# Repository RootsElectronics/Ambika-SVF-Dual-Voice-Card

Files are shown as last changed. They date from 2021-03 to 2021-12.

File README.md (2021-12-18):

# Ambika-SVF-Dual-Voice-Card
Adaptation of the Mutable Instruments Ambika SVF Voice Card in 0603 SMD, with 2 Voices per voice card

My initial prototype (verified working at 02/2021) utilised the original through hole zener diodes. On this version I have simply changed those for a surface mount equivalent. 

Will upload BOM soon, but for now:

There are a few of these out in the wild now, someone kindly noted a fix for calibration they were having on 2 out of their 3 voice cards.

To quote

"I swapped R10 and R32 to 36k and they all calibrated approximately in the middle of the range (it may be worth experimenting with the feedback cap as well I guess.... but I'm not going to !)"

Original design by émilie gillet

CC-BY-SA 3.0

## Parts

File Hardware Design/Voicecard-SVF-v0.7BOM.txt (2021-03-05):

Qty Value         Device                Package               Parts                                                                                                             Description                                                                             
4                 LED3MM                LED3MM                LED1, LED2, LED3, LED4                                                                                            LED                                                                                     
2                 M06SIP                1X06                  JP2, JP4                                                                                                          Header 6                                                                                
4   0             220OHM-0603-1/10W-1%  0603                  R61, R62, R63, R64                                                                                                220Ω resistor                                                                           
24  0.1uF         0.1UF-0603-25V-5%     0603                  C2, C4, C7, C8, C9, C13, C14, C17, C18, C22, C23, C24, C38, C39, C40, C41, C42, C43, C45, C49, C50, C51, C52, C55 0.1µF ceramic capacitors                                                                
2   1.0uF         1.0UF-0603-16V-10%    0603                  C28, C56                                                                                                          1µF ceramic capacitors                                                                  
2   100pF         100PF-0603-50V-5%     0603                  C3, C44                                                                                                           100pF/0.1nF ceramic capacitors                                                          
6   100u          CPOL-USC              PANASONIC_C           C1, C11, C27, C46, C53, C54                                                                                       POLARIZED CAPACITOR, American symbol                                                    
2   10k           10KOHM-0603-1/10W-1%  0603                  R29, R48                                                                                                          10kΩ resistor                                                                           
6   15k           15KOHM-0603-1/10W-1%  0603                  R9, R13, R19, R31, R38, R51                                                                                       15kΩ resistor                                                                           
4   18pF          18PF-0603-50V-5%      0603                  C25, C26, C36, C37                                                                                                18pF ceramic capacitors                                                                 
2   2.2k          2.2KOHM-0603-1/10W-1% 0603                  R12, R56                                                                                                          2.2kΩ resistor                                                                          
2   20MHz         CRYSTALHC49UP         HC49UP                Q3, Q4                                                                                                            CRYSTAL                                                                                 
6   220           220OHM-0603-1/10W-1%  0603                  R24, R27, R28, R53, R54, R55                                                                                      220Ω resistor                                                                           
4   220pF         270PF-0603-50V-5%     0603                  C10, C12, C30, C31                                                                                                270pF/0.27nF ceramic capacitors                                                         
2   330k          330KOHM-0603-1/10W-1% 0603                  R22, R46                                                                                                          330kΩ resistor                                                                          
24  33k           33KOHM-0603-1/10W-1%  0603                  R2, R5, R6, R7, R8, R10, R11, R14, R17, R18, R20, R21, R32, R34, R35, R36, R37, R39, R40, R45, R47, R57, R58, R59 33kΩ resistor                                                                           
2   33nF          33NF-0603-50V-10%     0603                  C19, C29                                                                                                          33nF ceramic capacitors                                                                 
4   4.7u          CPOL-USA              PANASONIC_A           C20, C21, C47, C48                                                                                                POLARIZED CAPACITOR, American symbol                                                    
14  470           470OHM-0603-1/10W-1%  0603                  R3, R4, R15, R16, R25, R26, R30, R41, R42, R43, R44, R49, R50, R60                                                470Ω resistor                                                                           
2   47k           47KOHM-0603-1/10W-1%  0603                  R1, R52                                                                                                           47kΩ resistor                                                                           
8   560pF         560PF-0603-50V-5%     0603                  C5, C6, C15, C16, C32, C33, C34, C35                                                                              0.56nF/560pF ceramic capacitors                                                         
2   5k            R-TRIMM3296P          RTRIM3296P            R23, R33                                                                                                          Trimm resistor                                                                          
2   ATMEGA328P-AU ATMEGA328P-AU         QFP80P900X900X120-32N U1, U3                                                                                                            ATmega Series 20 MHz 32 KB Flash 2 KB SRAM 8-Bit Microcontroller - TQFP-32 Check prices 
2   AVR_ISP       AVR_SPI_PRG_6PTH      2X3                   ISP_A, ISP_B                                                                                                      AVR ISP 6 Pin                                                                           
4   BSS138        BSS138                SOT95P240X111-3N      Q1, Q2, Q5, Q6                                                                                                    N-Channel 50V 220mA (Ta) 360mW (Ta) Surface Mount SOT-23-3  Check prices                
2   CD4052BM      CD4052BM              SOIC127P600X175-16N   U2, U4                                                                                                            Check prices                                                                            
2   MCP4822-E/SN  MCP4822-E/SN          SOIC127P599X175-8N    U$7, U7                                                                                                           Check prices                                                                            
4   MMSZ3V6T1G    MMSZ3V6T1G            SOD3716X135N          Z3, Z4, Z5, Z6                                                                                                    500 mW 3.6 V +/-5% ZenerDiodeVoltage Regulator                                          
2   MMSZ4V7T1G    MMSZ4V7T1G            SOD3716X135N          Z1, Z2                                                                                                            500 mW, 4.7 V +/-5% ZenerDiodeVoltage Regulator                                         
2   TL072         TL072_SMD             SO08                  IC1, IC6                                                                                                          Generic Dual Op Amp                                                                     
2   TL074         TL074_SMD             SO14                  IC3, IC5                                                                                                          Generic Quad Op Amp                                                                     
2   V2164D        SSM2164S              SOIC16N               IC2, IC4

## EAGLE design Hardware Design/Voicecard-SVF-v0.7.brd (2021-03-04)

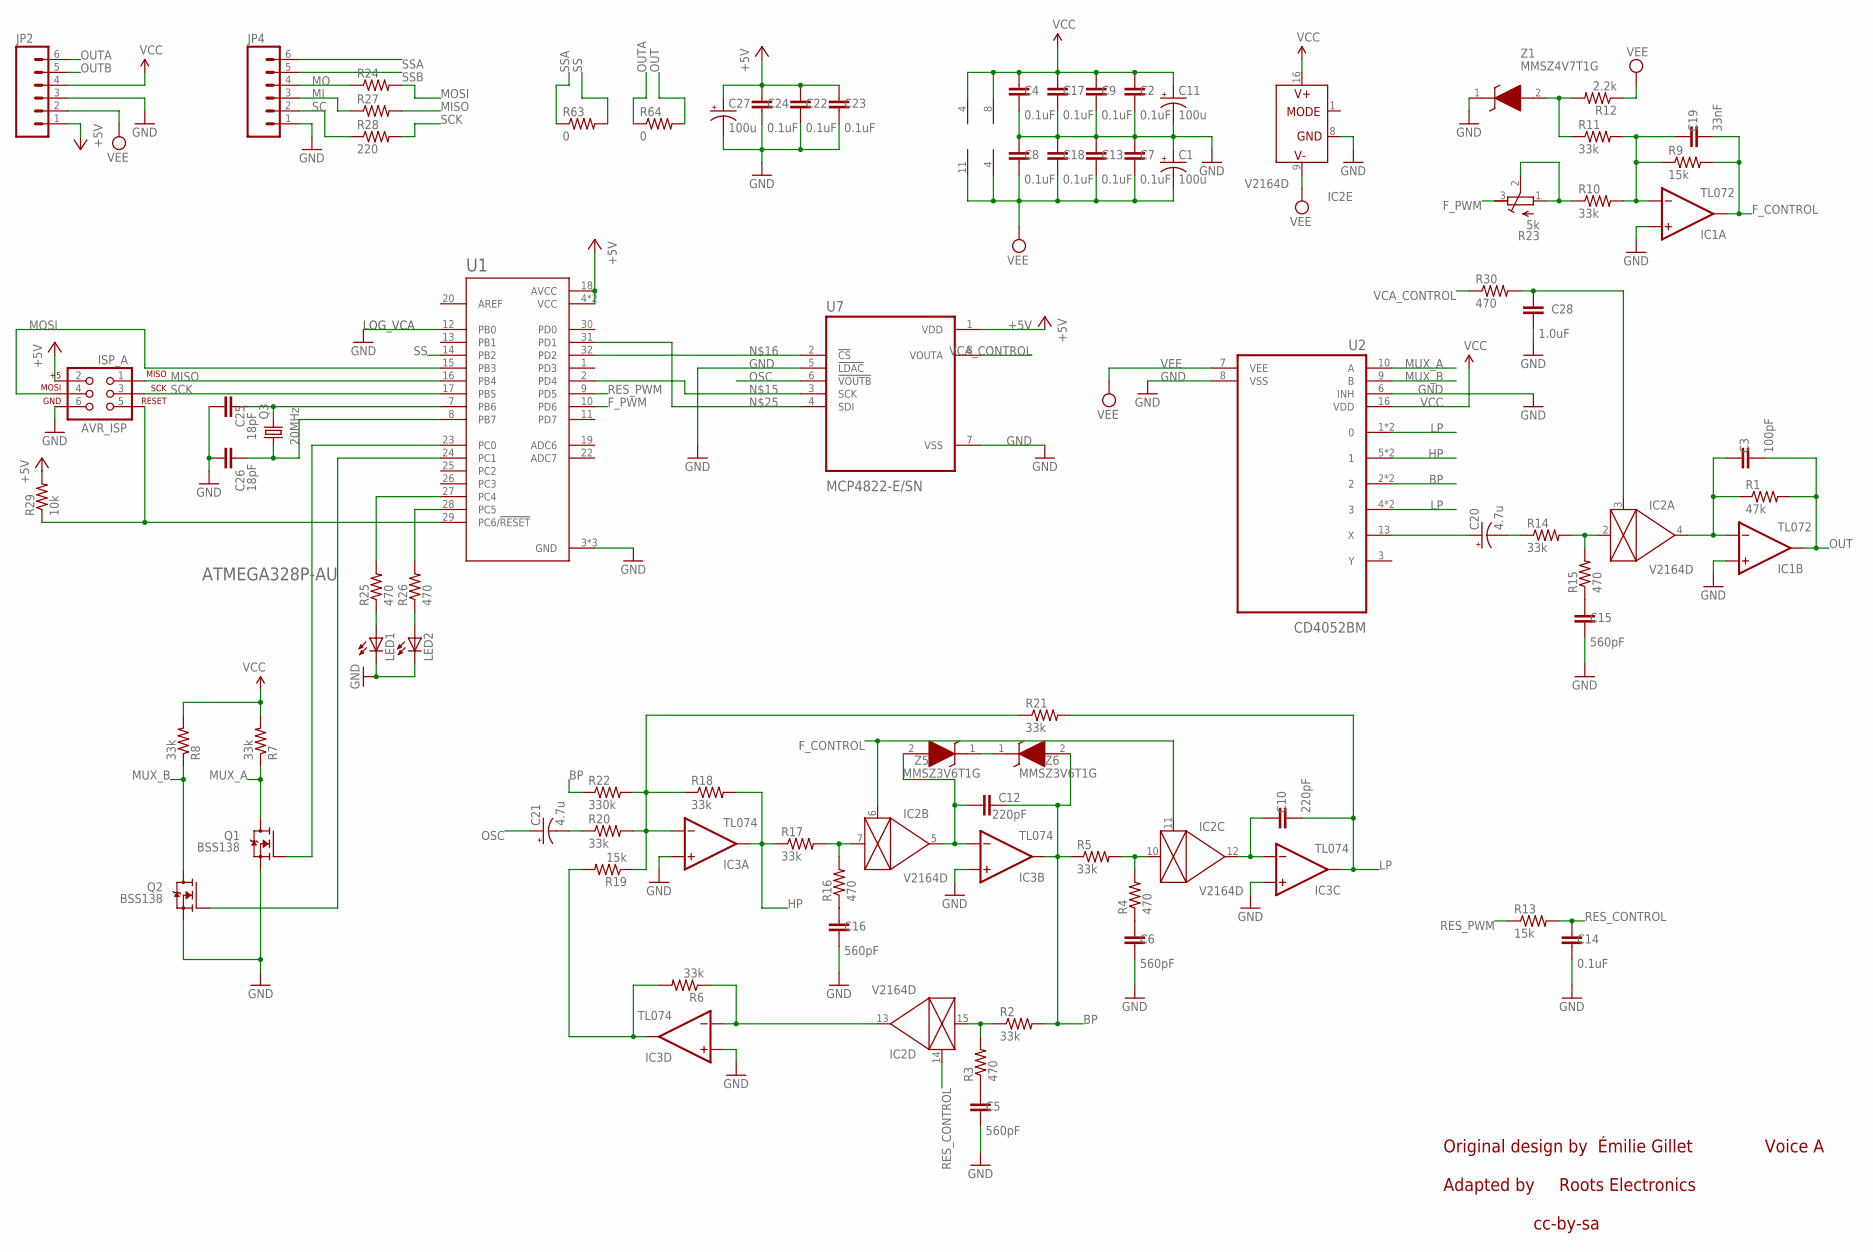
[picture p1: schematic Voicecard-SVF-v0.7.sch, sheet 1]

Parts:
C1, C11, C27: 100u; PANASONIC_C
C2, C4, C7, C8, C9, C13, C14, C17, C18, C22, C23, C24: 0.1uF; 0603
C3: 100pF; 0603
C5, C6, C15, C16: 560pF; 0603
C10, C12: 220pF; 0603
C19: 33nF; 0603
C20, C21: 4.7u; PANASONIC_A
C25, C26: 18pF; 0603
C28: 1.0uF; 0603
IC1: TL072; SO08
IC2: V2164D; SOIC16N
IC3: TL074; SO14
ISP_A: AVR_ISP; 2X3
JP2, JP4: M06SIP; 1X06
LED1, LED2: LED3MM
Q1, Q2: BSS138; SOT95P240X111-3N
Q3: 20MHz; HC49UP
R1: 47k; 0603
R2, R5, R6, R7, R8, R10, R11, R14, R17, R18, R20, R21: 33k; 0603
R3, R4, R15, R16, R25, R26, R30: 470; 0603
R9, R13, R19: 15k; 0603
R12: 2.2k; 0603
R22: 330k; 0603
R23: 5k; RTRIM3296P
R24, R27, R28: 220; 0603
R29: 10k; 0603
R63, R64: 0; 0603
U1: ATMEGA328P-AU; QFP80P900X900X120-32N
U2: CD4052BM; SOIC127P600X175-16N
U7: MCP4822-E/SN; SOIC127P599X175-8N
Z1: MMSZ4V7T1G; SOD3716X135N
Z5, Z6: MMSZ3V6T1G; SOD3716X135N

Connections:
+5V: C22.1, C23.1, C24.1, C27.+, ISP_A.2, JP2.1, R29.2, U1.4 (VCC), U1.6 (VCC), U1.18 (AVCC), U7.1 (VDD); also elsewhere on the board
BP: C12.2, IC3.7 (OUT), R2.2, R5.1, R22.1, U2.2, U2.15 (2), Z6.2 (A)
F_CONTROL: C19.2, IC1.1 (OUT), IC2.6 (CTRL), IC2.11 (CTRL), R9.2
F_PWM: R23.3 (A), U1.10 (PD6)
GND: C1.+, C2.2, C4.2, C5.2, C6.2, C7.1, C8.1, C9.2, C11.-, C13.1, C14.2, C15.2, C16.2, C17.2, C18.1, C22.2, C23.2, C24.2, C25.1, C26.1, C27.-, C28.2, IC1.3 (+IN), IC1.5 (+IN), IC2.8 (GND), IC3.3 (+IN), IC3.5 (+IN), IC3.10 (+IN), IC3.12 (+IN), ISP_A.6, JP2.3, JP4.1, LED1.K (C), LED2.K (C), Q1.2 (S), Q2.2 (S), U1.3 (GND), U1.5 (GND), U1.12 (PB0), U1.21 (GND), U2.6 (INH), U2.8 (VSS), U7.5 (!LDAC), U7.7 (VSS), Z1.1 (K); also elsewhere on the board
HP: IC3.1 (OUT), R17.1, R18.2, U2.5 (1), U2.14 (1)
LEDS0: R25.2, U1.27 (PC4)
LP: C10.2, IC3.8 (OUT), R21.2, U2.1 (0), U2.4 (3), U2.11 (3), U2.12 (0)
MI: JP4.3, R27.1; also elsewhere on the board
MISO: ISP_A.1, R27.2, U1.16 (PB4)
MO: JP4.4, R24.1; also elsewhere on the board
MOSI: ISP_A.4, R24.2, U1.15 (PB3)
MUX_A: Q1.3 (D), R7.1, U2.10 (A)
MUX_B: Q2.3 (D), R8.1, U2.9 (B)
unnamed: C21.-, R20.1
unnamed: C20.+, U2.13 (X)
unnamed: Q1.1 (G), U1.23 (PC0)
unnamed: C20.-, R14.1
unnamed: Q2.1 (G), U1.24 (PC1)
unnamed: LED1.A, R25.1
unnamed: R11.1, R12.2, Z1.2 (A)
unnamed: LED2.A, R26.1
unnamed: R26.2, U1.28 (PC5)
unnamed: IC3.2 (-IN), R18.1, R19.1, R20.2, R21.1, R22.2
unnamed: U1.2 (PD4), U7.3 (SCK)
unnamed: U1.32 (PD2), U7.2 (!CS)
unnamed: C6.1, R4.1
unnamed: C12.1, IC2.5 (OUT), IC3.6 (-IN), Z5.2 (A)
unnamed: IC2.15 (IN), R2.1, R3.2
unnamed: ISP_A.5, R29.1, U1.29 (PC6/!RESET)
unnamed: U1.31 (PD1), U7.4 (SDI)
unnamed: IC2.10 (IN), R4.2, R5.2
unnamed: C5.1, R3.1
unnamed: C10.1, IC2.12 (OUT), IC3.9 (-IN)
unnamed: IC2.7 (IN), R16.2, R17.2
unnamed: C16.1, R16.1
unnamed: IC2.13 (OUT), IC3.13 (-IN), R6.1
unnamed: C19.1, IC1.2 (-IN), R9.1, R10.2, R11.2
unnamed: R10.1, R23.1 (E), R23.2 (S)
unnamed: IC3.14 (OUT), R6.2, R19.2
unnamed: Z5.1 (K), Z6.1 (K)
unnamed: C15.1, R15.1
unnamed: IC2.2 (IN), R14.2, R15.2
unnamed: C3.1, IC1.6 (-IN), IC2.4 (OUT), R1.1
unnamed: C26.2, Q3.1, U1.8 (PB7)
unnamed: C25.2, Q3.2, U1.7 (PB6)
NET55: C28.1, IC2.3 (CTRL), R30.2
OSC: C21.+, U7.6 (!VOUTB)
OUT: C3.2, IC1.7 (OUT), R1.2, R64.2
OUTA: JP2.6, R64.1
OUTB: JP2.5; also elsewhere on the board
RES_CONTROL: C14.1, IC2.14 (CTRL), R13.2
RES_PWM: R13.1, U1.9 (PD5)
SC: JP4.2, R28.1; also elsewhere on the board
SCK: ISP_A.3, R28.2, U1.17 (PB5)
SS: R63.2, U1.14 (PB2)
SSA: JP4.6, R63.1
SSB: JP4.5; also elsewhere on the board
VCA_CONTROL: R30.1, U7.8 (VOUTA)
VCC: C2.1, C4.1, C9.1, C11.+, C17.1, IC1.8 (V+), IC2.16 (V+), IC3.4 (V+), JP2.4, R7.2, R8.2, U2.16 (VDD); also elsewhere on the board
VEE: C1.-, C7.2, C8.2, C13.2, C18.2, IC1.4 (V-), IC2.9 (V-), IC3.11 (V-), JP2.2, R12.1, U2.7 (VEE); also elsewhere on the board

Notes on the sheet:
Original design by
Émilie Gillet
LOG_VCA
Voice A
cc-by-sa
Adapted by
Roots Electronics

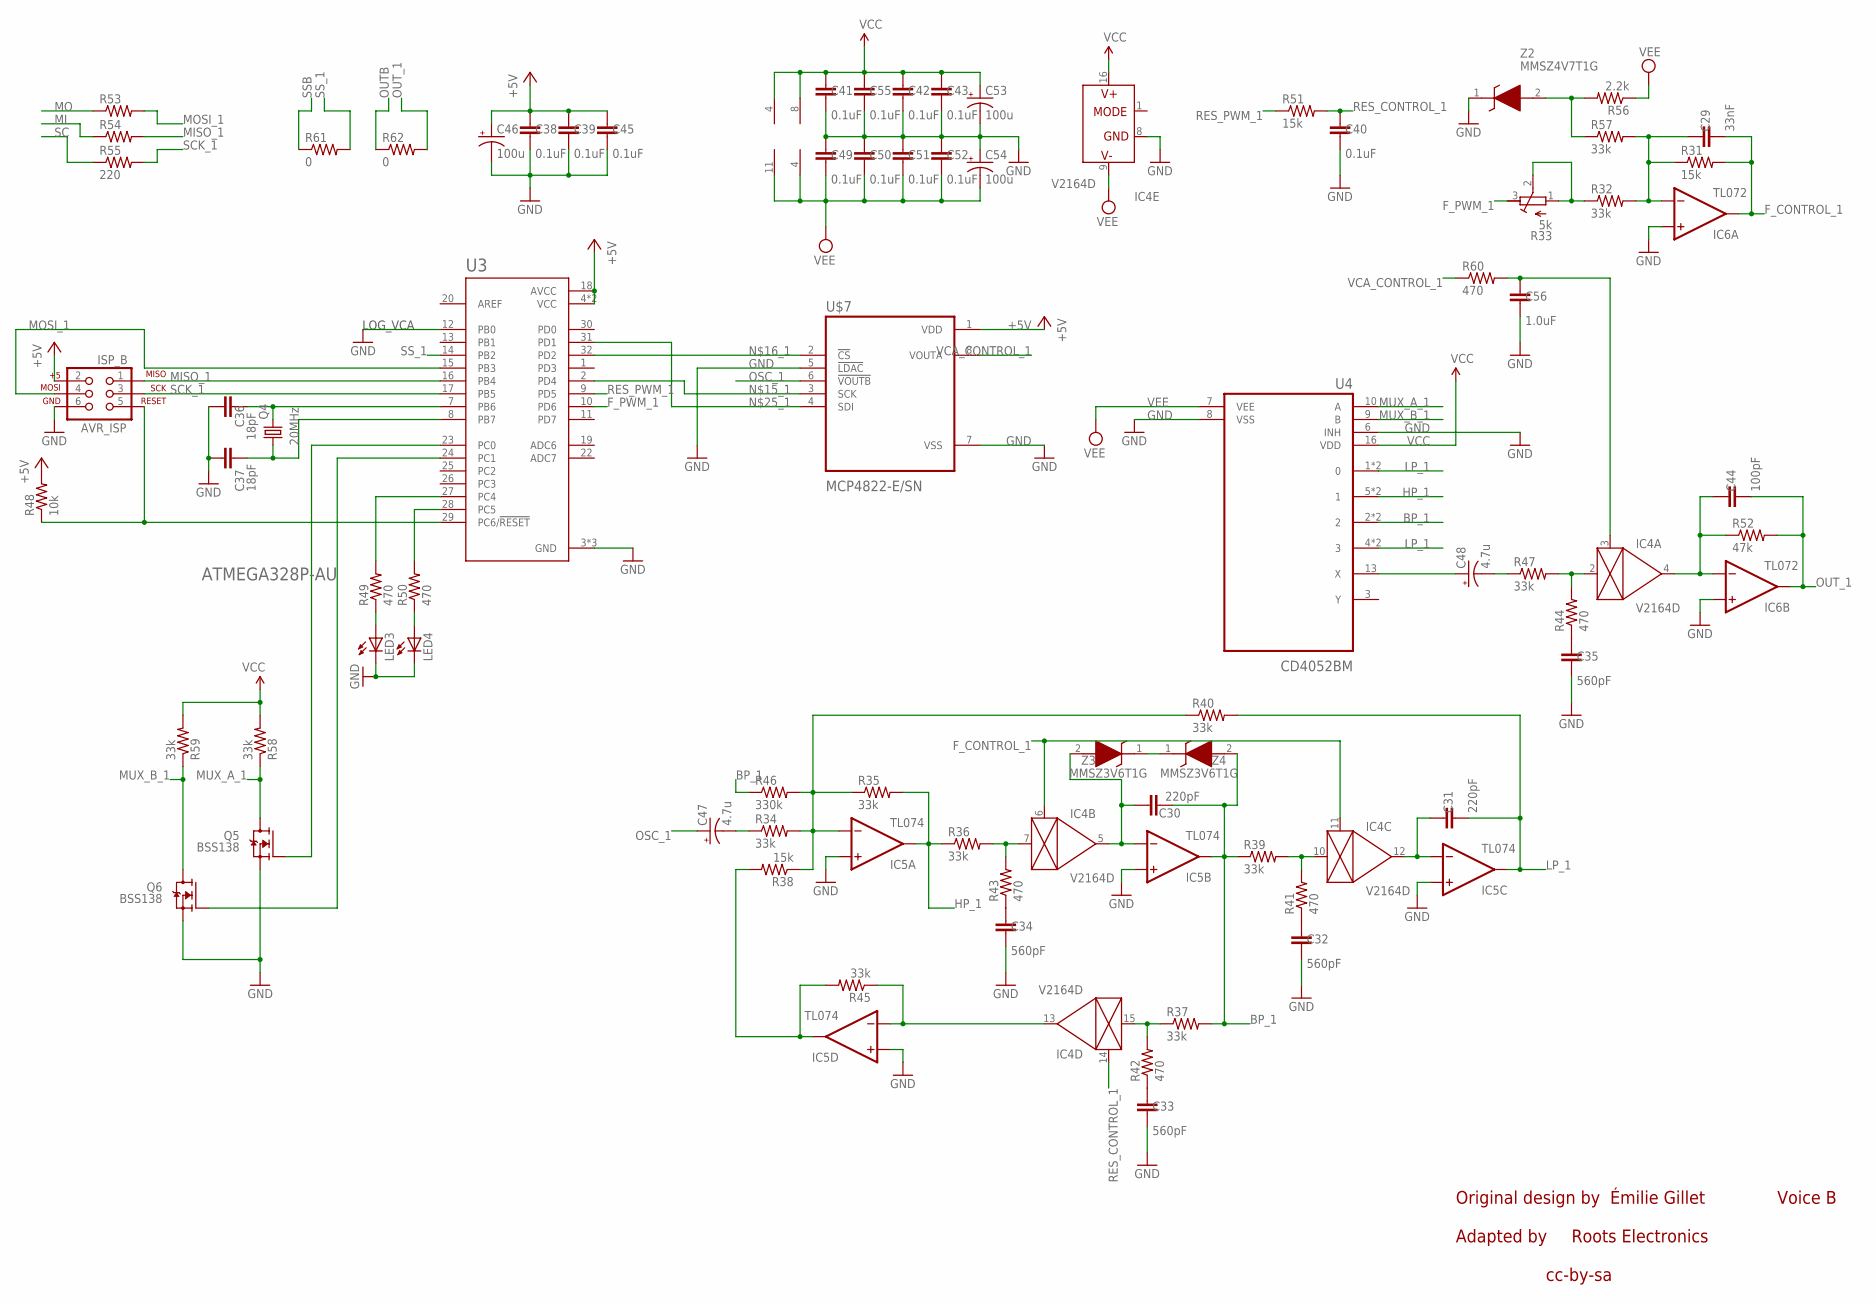
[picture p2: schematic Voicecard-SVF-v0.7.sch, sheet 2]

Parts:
C29: 33nF; 0603
C30, C31: 220pF; 0603
C32, C33, C34, C35: 560pF; 0603
C36, C37: 18pF; 0603
C38, C39, C40, C41, C42, C43, C45, C49, C50, C51, C52, C55: 0.1uF; 0603
C44: 100pF; 0603
C46, C53, C54: 100u; PANASONIC_C
C47, C48: 4.7u; PANASONIC_A
C56: 1.0uF; 0603
IC4: V2164D; SOIC16N
IC5: TL074; SO14
IC6: TL072; SO08
ISP_B: AVR_ISP; 2X3
LED3, LED4: LED3MM
Q4: 20MHz; HC49UP
Q5, Q6: BSS138; SOT95P240X111-3N
R31, R38, R51: 15k; 0603
R32, R34, R35, R36, R37, R39, R40, R45, R47, R57, R58, R59: 33k; 0603
R33: 5k; RTRIM3296P
R41, R42, R43, R44, R49, R50, R60: 470; 0603
R46: 330k; 0603
R48: 10k; 0603
R52: 47k; 0603
R53, R54, R55: 220; 0603
R56: 2.2k; 0603
R61, R62: 0; 0603
U3: ATMEGA328P-AU; QFP80P900X900X120-32N
U4: CD4052BM; SOIC127P600X175-16N
U$7: MCP4822-E/SN; SOIC127P599X175-8N
Z2: MMSZ4V7T1G; SOD3716X135N
Z3, Z4: MMSZ3V6T1G; SOD3716X135N

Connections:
+5V: C38.1, C39.1, C45.1, C46.+, ISP_B.2, R48.2, U3.4 (VCC), U3.6 (VCC), U3.18 (AVCC), U$7.1 (VDD); also elsewhere on the board
BP_1: C30.2, IC5.7 (OUT), R37.2, R39.1, R46.1, U4.2, U4.15 (2), Z4.2 (A)
F_CONTROL_1: C29.2, IC4.6 (CTRL), IC4.11 (CTRL), IC6.1 (OUT), R31.2
F_PWM_1: R33.3 (A), U3.10 (PD6)
GND: C32.2, C33.2, C34.2, C35.2, C36.1, C37.1, C38.2, C39.2, C40.2, C41.2, C42.2, C43.2, C45.2, C46.-, C49.1, C50.1, C51.1, C52.1, C53.-, C54.+, C55.2, C56.2, IC4.8 (GND), IC5.3 (+IN), IC5.5 (+IN), IC5.10 (+IN), IC5.12 (+IN), IC6.3 (+IN), IC6.5 (+IN), ISP_B.6, LED3.K (C), LED4.K (C), Q5.2 (S), Q6.2 (S), U3.3 (GND), U3.5 (GND), U3.12 (PB0), U3.21 (GND), U4.6 (INH), U4.8 (VSS), U$7.5 (!LDAC), U$7.7 (VSS), Z2.1 (K); also elsewhere on the board
HP_1: IC5.1 (OUT), R35.2, R36.1, U4.5 (1), U4.14 (1)
LEDS1_1: R49.2, U3.27 (PC4)
LP_1: C31.2, IC5.8 (OUT), R40.2, U4.1 (0), U4.4 (3), U4.11 (3), U4.12 (0)
MI: R54.1; also elsewhere on the board
MISO_1: ISP_B.1, R54.2, U3.16 (PB4)
MO: R53.1; also elsewhere on the board
MOSI_1: ISP_B.4, R53.2, U3.15 (PB3)
MUX_A_1: Q5.3 (D), R58.1, U4.10 (A)
MUX_B_1: Q6.3 (D), R59.1, U4.9 (B)
unnamed: C29.1, IC6.2 (-IN), R31.1, R32.2, R57.2
unnamed: R32.1, R33.1 (E), R33.2 (S)
unnamed: C44.1, IC4.4 (OUT), IC6.6 (-IN), R52.1
unnamed: IC5.2 (-IN), R34.2, R35.1, R38.1, R40.1, R46.2
unnamed: U3.2 (PD4), U$7.3 (SCK)
unnamed: U3.32 (PD2), U$7.2 (!CS)
unnamed: C30.1, IC4.5 (OUT), IC5.6 (-IN), Z3.2 (A)
unnamed: IC4.10 (IN), R39.2, R41.2
unnamed: C31.1, IC4.12 (OUT), IC5.9 (-IN)
unnamed: C32.1, R41.1
unnamed: U3.31 (PD1), U$7.4 (SDI)
unnamed: C33.1, R42.1
unnamed: IC4.7 (IN), R36.2, R43.2
unnamed: C34.1, R43.1
unnamed: C35.1, R44.1
unnamed: IC4.2 (IN), R44.2, R47.2
unnamed: IC4.15 (IN), R37.1, R42.2
unnamed: IC4.13 (OUT), IC5.13 (-IN), R45.1
unnamed: IC5.14 (OUT), R38.2, R45.2
unnamed: Z3.1 (K), Z4.1 (K)
unnamed: C47.-, R34.1
unnamed: C48.-, R47.1
unnamed: C37.2, Q4.1, U3.8 (PB7)
unnamed: C36.2, Q4.2, U3.7 (PB6)
unnamed: LED3.A, R49.1
unnamed: LED4.A, R50.1
unnamed: R50.2, U3.28 (PC5)
unnamed: R56.2, R57.1, Z2.2 (A)
unnamed: ISP_B.5, R48.1, U3.29 (PC6/!RESET)
unnamed: Q5.1 (G), U3.23 (PC0)
unnamed: Q6.1 (G), U3.24 (PC1)
unnamed: C48.+, U4.13 (X)
NET1: C56.1, IC4.3 (CTRL), R60.2
OSC_1: C47.+, U$7.6 (!VOUTB)
OUTB: R62.1; also elsewhere on the board
OUT_1: C44.2, IC6.7 (OUT), R52.2, R62.2
RES_CONTROL_1: C40.1, IC4.14 (CTRL), R51.2
RES_PWM_1: R51.1, U3.9 (PD5)
SC: R55.1; also elsewhere on the board
SCK_1: ISP_B.3, R55.2, U3.17 (PB5)
SSB: R61.1; also elsewhere on the board
SS_1: R61.2, U3.14 (PB2)
VCA_CONTROL_1: R60.1, U$7.8 (VOUTA)
VCC: C41.1, C42.1, C43.1, C53.+, C55.1, IC4.16 (V+), IC5.4 (V+), IC6.8 (V+), R58.2, R59.2, U4.16 (VDD); also elsewhere on the board
VEE: C49.2, C50.2, C51.2, C52.2, C54.-, IC4.9 (V-), IC5.11 (V-), IC6.4 (V-), R56.1, U4.7 (VEE); also elsewhere on the board

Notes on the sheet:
LOG_VCA
Voice B
Original design by
Émilie Gillet
cc-by-sa
Adapted by
Roots Electronics

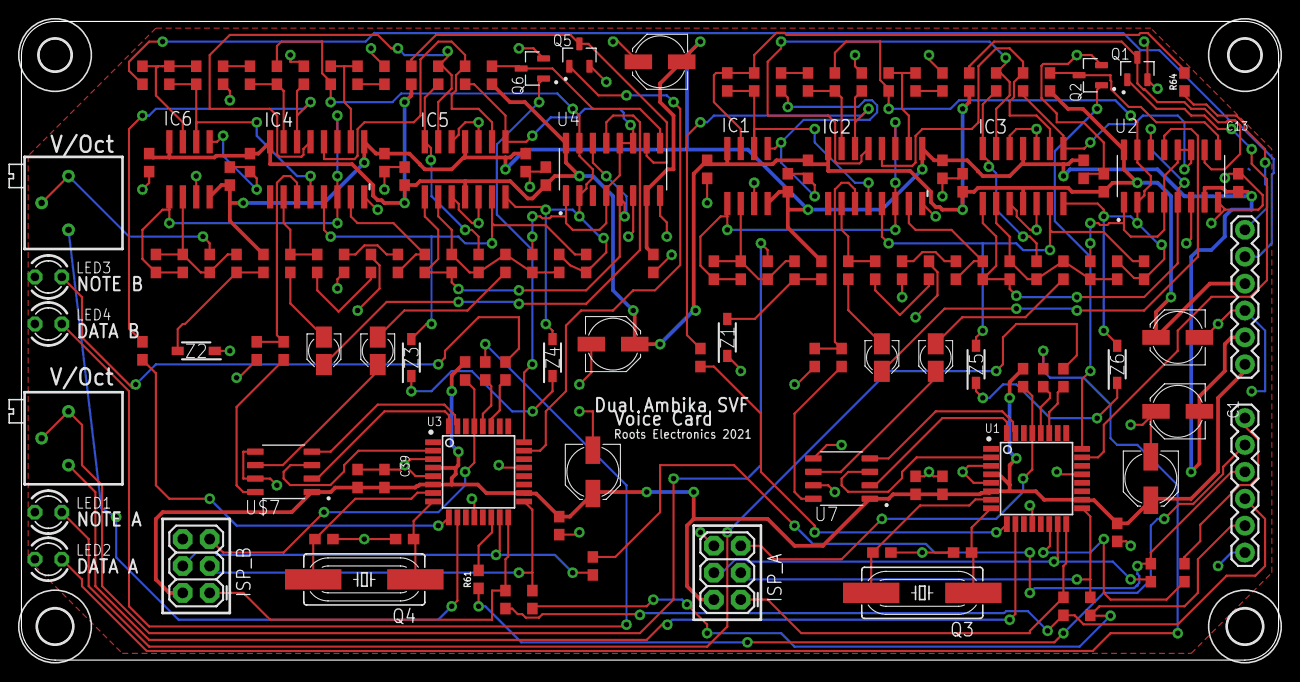
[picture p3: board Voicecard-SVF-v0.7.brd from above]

Board: 2 copper layers, 118.7 x 60.3 mm, 156 parts (0 on the bottom side), 111 nets.

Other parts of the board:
U$1, U$2: 3,0
U$5, U$6: 3,3

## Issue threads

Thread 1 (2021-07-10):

Flashing successful with R53/R54/R55 in place.

ob1techno, 2021-07-10:
I just wanted to note that I flashed 3 fully assembled voice cards with all resistors in place with no problems, despite the note in the ReadMe.

😊

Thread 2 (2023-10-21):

Part for C1, C27

6040, 2023-10-21:
Hi can anybody that built one of these bad boys tell me what part to use for C1, C27?
The pcb manufacturer tells me all parts I select will not fit here.
Thanks
6040

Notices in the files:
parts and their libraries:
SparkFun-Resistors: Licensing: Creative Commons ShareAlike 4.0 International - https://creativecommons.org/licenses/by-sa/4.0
